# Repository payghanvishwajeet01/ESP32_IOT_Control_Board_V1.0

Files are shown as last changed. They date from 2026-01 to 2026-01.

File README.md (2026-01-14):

The ESP32_IOT_Control_Board_V1.0 is a compact, ESP32-based control board designed for smart home and industrial automation applications. 
It integrates Wi-Fi and BLE connectivity, enabling seamless cloud and local communication. 
The board features 4-channel relay outputs for reliable control of AC and DC loads. 
An onboard flame detection sensor interface enhances safety and monitoring capabilities. 
The power section supports a wide input range (90–264V AC) with onboard regulation for stable 5V and 3.3V outputs. 
Auto-reset and auto-boot circuitry simplify firmware uploading and development. 
Built-in protection components such as polyfuse, TVS diodes, and flyback diodes improve reliability. 
User-programmable status and relay LEDs provide real-time visual feedback. Multiple GPIO, UART, and I²C interfaces allow easy expansion with external sensors and modules. 
Overall, the board is optimized for robust, scalable, and production-ready IoT solutions.
# ESP32_IoT_Control_Board_V1.0

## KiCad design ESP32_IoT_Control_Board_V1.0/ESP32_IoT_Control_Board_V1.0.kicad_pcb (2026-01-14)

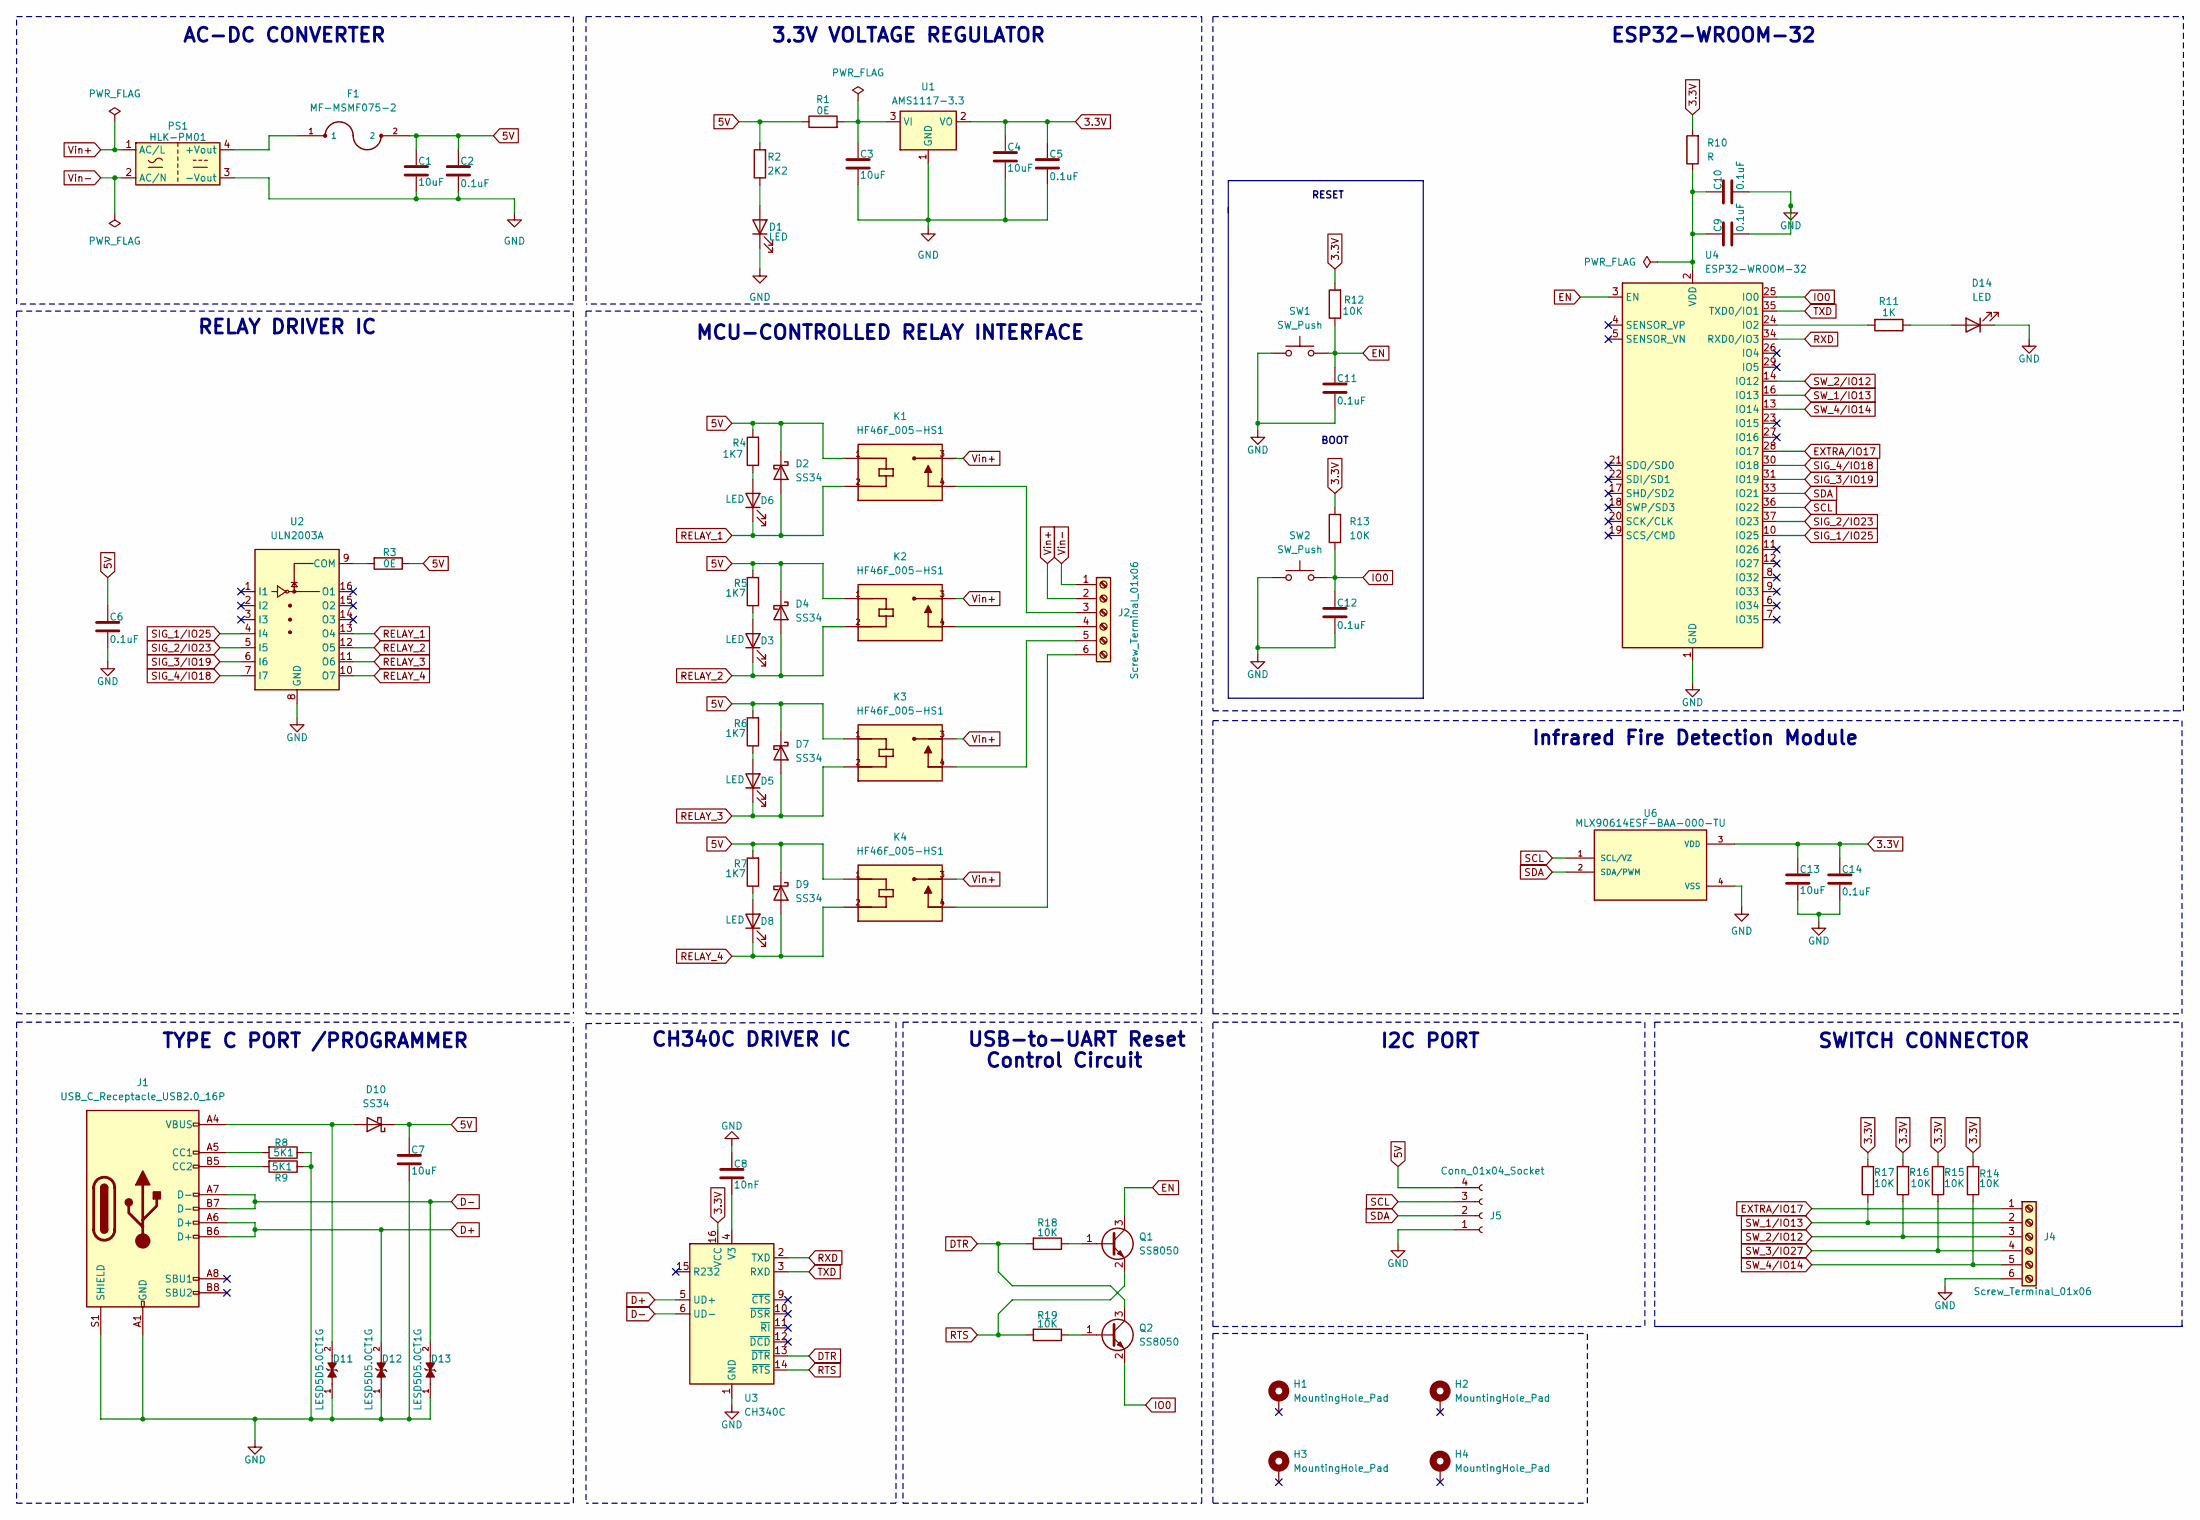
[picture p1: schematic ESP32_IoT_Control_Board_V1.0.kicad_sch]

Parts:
C1, C3, C4, C7, C13: 10uF; C_0805_2012Metric
C2, C5, C6, C9, C10, C11, C12, C14: 0.1uF; C_0603_1608Metric
C8: 10nF; C_0603_1608Metric
D1, D3, D5, D6, D8, D14: LED; LED_0603_1608Metric
D2, D4, D7, D9, D10: SS34; D_SMA
D11, D12, D13: LESD5D5.0CT1G; TVS_LESD5D5.0CT1G; PARTREV O
F1: MF-MSMF075-2; FUSM4632X85
H1, H2, H3, H4: MountingHole_Pad; MountingHole_2.5mm_Pad_Via
J1: USB_C_Receptacle_USB2.0_16P; AMPHENOL_12402012E212A
J2, J4: Screw_Terminal_01x06; TerminalBlock_MaiXu_MX126-5.0-06P_1x06_P5.00mm
J5: Conn_01x04_Socket; PinSocket_1x04_P2.54mm_Vertical
K1, K2, K3, K4: HF46F_005-HS1; RELAY_HF46F_005-HS1; PARTREV 1.00
PS1: HLK-PM01; Converter_ACDC_Hi-Link_HLK-PMxx
Q1, Q2: SS8050; SOT-23
R1, R3: 0E; R_0603_1608Metric
R2: 2K2; R_0603_1608Metric
R4, R5, R6, R7: 1K7; R_0603_1608Metric
R8, R9: 5K1; R_0603_1608Metric
R10: R; R_0603_1608Metric
R11: 1K; R_0603_1608Metric
R12, R13, R14, R15, R16, R17, R18, R19: 10K; R_0603_1608Metric
SW1, SW2: SW_Push; SW_SKRPABE010
U1: AMS1117-3.3; SOT-223-3_TabPin2
U2: ULN2003A; SOIC127P600X175-16N
U3: CH340C; SOIC-16_3.9x9.9mm_P1.27mm
U4: ESP32-WROOM-32
U6: MLX90614ESF-BAA-000-TU; TO254P942H425-4; PARTREV 13

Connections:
3.3V: C4.1, C5.1, C13.1, C14.1, R10.2, R12.2, R13.2, R14.2, R15.2, R16.2, R17.2, U1.2 (VO), U3.16 (VCC), U6.3 (VDD)
5V: C1.1, C2.1, C6.1, C7.1, D2.1 (K), D4.1 (K), D7.1 (K), D9.1 (K), D10.1 (K), F1.2, J5.4, K1.1, K2.1, K3.1, K4.1, R1.1, R2.2, R3.1, R4.2, R5.2, R6.2, R7.2
D+: D12.2, J1.A6 (D+), J1.B6 (D+), U3.5 (UD+)
D-: D13.2, J1.A7 (D-), J1.B7 (D-), U3.6 (UD-)
DTR: Q2.3 (C), R18.2, U3.13 (~DTR)
EN: C11.1, Q1.3 (C), R12.1, SW1.2, U4.3 (EN)
EXTRA/IO17: J4.1, U4.28 (IO17)
GND: C1.2, C2.2, C3.2, C4.2, C5.2, C6.2, C7.2, C8.1, C9.2, C10.2, C11.2, C12.2, C13.2, C14.2, D1.1 (K), D11.1, D12.1, D13.1, D14.1 (K), J1.A1 (GND), J1.A12 (GND), J1.B1 (GND), J1.B12 (GND), J1.S1 (SHIELD), J4.6, J5.1, PS1.3 (-Vout), R8.1, R9.1, SW1.1, SW2.1, U1.1 (GND), U2.8 (GND), U3.1 (GND), U4.1 (GND), U4.15 (GND), U4.38 (GND), U4.39 (GND), U6.4 (VSS)
IO0: C12.1, Q2.2 (E), R13.1, SW2.2, U4.25 (IO0)
unnamed: D1.2 (A), R2.1
unnamed: D3.2 (A), R5.1
unnamed: D5.2 (A), R6.1
unnamed: D6.2 (A), R4.1
unnamed: D8.2 (A), R7.1
unnamed: D10.2 (A), D11.2, J1.A4 (VBUS), J1.A9 (VBUS), J1.B4 (VBUS), J1.B9 (VBUS)
unnamed: D14.2 (A), R11.1
unnamed: J1.A5 (CC1), R8.2
unnamed: J1.B5 (CC2), R9.2
unnamed: J2.3, K1.4
unnamed: J2.4, K2.4
unnamed: J2.5, K3.4
unnamed: J2.6, K4.4
unnamed: F1.1, PS1.4 (+Vout)
unnamed: Q1.1 (B), R18.1
unnamed: Q2.1 (B), R19.1
unnamed: C3.1, R1.2, U1.3 (VI)
unnamed: R3.2, U2.9 (COM)
unnamed: C8.2, U3.4 (V3)
unnamed: R11.2, U4.24 (IO2)
unnamed: C9.1, C10.1, R10.1, U4.2 (VDD)
RELAY_1: D2.2 (A), D6.1 (K), K1.2, U2.13 (O4)
RELAY_2: D3.1 (K), D4.2 (A), K2.2, U2.12 (O5)
RELAY_3: D5.1 (K), D7.2 (A), K3.2, U2.11 (O6)
RELAY_4: D8.1 (K), D9.2 (A), K4.2, U2.10 (O7)
RTS: Q1.2 (E), R19.2, U3.14 (~RTS)
RXD: U3.2 (TXD), U4.34 (RXD0/IO3)
SCL: J5.3, U4.36 (IO22), U6.1 (SCL/VZ)
SDA: J5.2, U4.33 (IO21), U6.2 (SDA/PWM)
SIG_1/IO25: U2.4 (I4), U4.10 (IO25)
SIG_2/IO23: U2.5 (I5), U4.37 (IO23)
SIG_3/IO19: U2.6 (I6), U4.31 (IO19)
SIG_4/IO18: U2.7 (I7), U4.30 (IO18)
SW_1/IO13: J4.2, R17.1, U4.16 (IO13)
SW_2/IO12: J4.3, R16.1, U4.14 (IO12)
SW_3/IO27: J4.4, R15.1
SW_4/IO14: J4.5, R14.1, U4.13 (IO14)
TXD: U3.3 (RXD), U4.35 (TXD0/IO1)
Vin+: J2.2, K1.3, K2.3, K3.3, K4.3, PS1.1 (AC/L)
Vin-: J2.1, PS1.2 (AC/N)

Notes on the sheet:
BOOT
RESET
AC-DC CONVERTER
RELAY DRIVER IC
3.3V VOLTAGE REGULATOR
TYPE C PORT /PROGRAMMER
USB-to-UART Reset
I2C PORT
Infrared Fire Detection Module
SWITCH CONNECTOR
CH340C DRIVER IC
ESP32-WROOM-32
Control Circuit
MCU-CONTROLLED RELAY INTERFACE

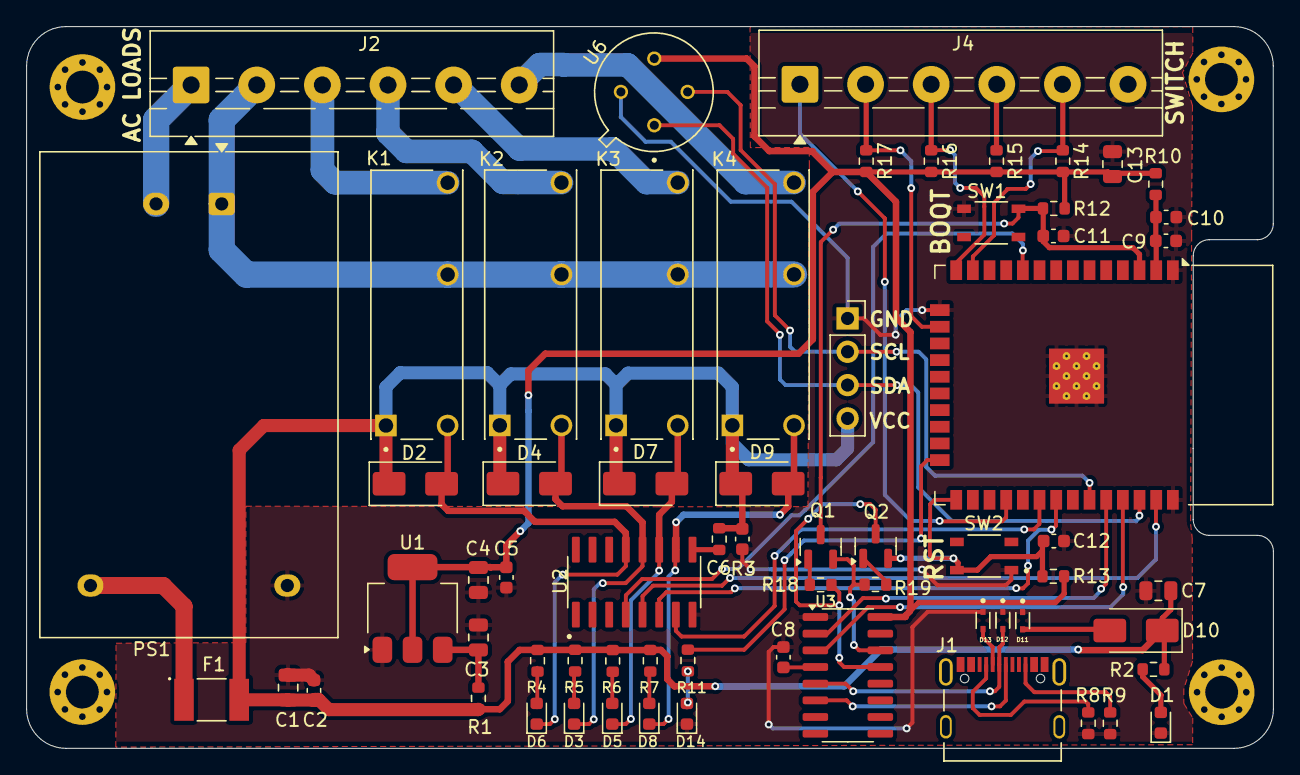
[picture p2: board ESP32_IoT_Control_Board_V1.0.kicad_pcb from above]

Board: 2 copper layers, 95.0 x 55.0 mm, 70 parts (1 on the bottom side), 49 nets.

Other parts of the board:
QR*****: ESP_IOT
